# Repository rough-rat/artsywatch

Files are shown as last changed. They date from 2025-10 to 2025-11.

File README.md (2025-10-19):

# artsywatch

## Licensing Note

This project uses footprints, symbols and and 3D models converted via the
[easy2kicad](https://github.com/uPesy/easyeda2kicad.py) project.
These are derived from publicly available EasyEDA/JLCPCB component data,
used here solely to support reproducibility of this open hardware design.
All trademarks and component data belong to their respective owners.

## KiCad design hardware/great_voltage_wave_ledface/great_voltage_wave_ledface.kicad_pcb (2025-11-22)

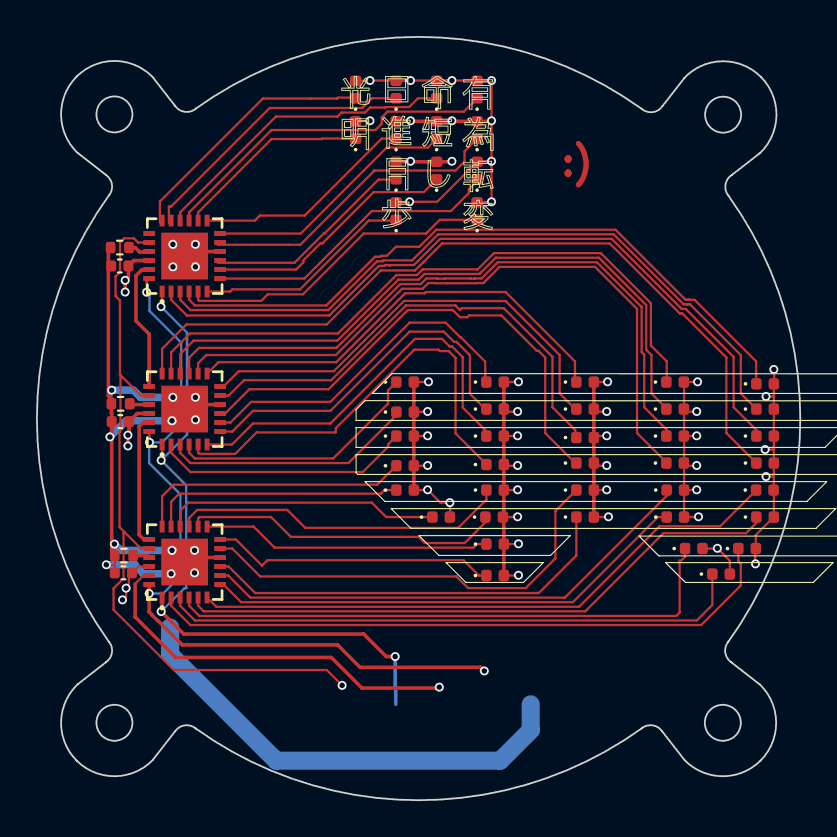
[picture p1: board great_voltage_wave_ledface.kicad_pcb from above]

Board: 2 copper layers, 42.4 x 42.4 mm, 58 parts (1 on the bottom side), 59 nets.

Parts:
C3, C10, C16: 470n; C_0402_1005Metric
D3, D4, D5, D6, D7, D8, D9, D10, D11, D12, D13, D14, D15, D16, D17, D18, D19, D20, D21, D22, D23, D24, D25, D26, D27, D28, D29, D30, D31, D32, D33, D34, D35, D36, D37, D38, D39, D40, D41, D42, D43, D44, D45, D46, D47, D48, D49, D50: LED; LED_0402_1005Metric
J1: Conn_01x06; CONN-SMD_GT-BTP25006-0300A-010A
R14, R16, R19: 510; R_0402_1005Metric
U101, U102, U103: FM6126QC; TQFN-24_L4.0-W4.0-P0.50-BL-EP2.6

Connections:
/DAT: J1.4, U101.23 (SDI)
/LAT: J1.3, U101.1 (LE), U102.1 (LE), U103.1 (LE)
/OE: J1.2, U101.20 (OE), U102.20 (OE), U103.20 (OE)
/SCLK: J1.5, U101.24 (CLK), U102.24 (CLK), U103.24 (CLK)
GND: C3.2, C10.2, C16.2, J1.6, R14.2, R16.2, R19.2, U101.10 (GND), U101.25 (EP), U102.10 (GND), U102.25 (EP), U103.10 (GND), U103.25 (EP)
unnamed: D3.1 (K), U103.18 (~OUT15)
unnamed: D4.1 (K), U103.17 (~OUT14)
unnamed: D5.1 (K), U103.16 (~OUT13)
unnamed: D6.1 (K), U103.15 (~OUT12)
unnamed: D7.1 (K), U103.14 (~OUT11)
unnamed: D8.1 (K), U103.13 (~OUT10)
unnamed: D9.1 (K), U103.12 (~OUT9)
unnamed: D10.1 (K), U103.11 (~OUT8)
unnamed: D11.1 (K), U103.9 (~OUT7)
unnamed: D12.1 (K), U103.8 (~OUT6)
unnamed: D13.1 (K), U103.7 (~OUT5)
unnamed: D14.1 (K), U103.6 (~OUT4)
unnamed: D15.1 (K), U103.5 (~OUT3)
unnamed: D16.1 (K), U103.4 (~OUT2)
unnamed: D17.1 (K), U103.3 (~OUT1)
unnamed: D18.1 (K), U103.2 (~OUT0)
unnamed: D19.1 (K), U102.2 (~OUT0)
unnamed: D20.1 (K), U102.3 (~OUT1)
unnamed: D21.1 (K), U102.4 (~OUT2)
unnamed: D22.1 (K), U102.5 (~OUT3)
unnamed: D23.1 (K), U102.6 (~OUT4)
unnamed: D24.1 (K), U102.7 (~OUT5)
unnamed: D25.1 (K), U102.8 (~OUT6)
unnamed: D26.1 (K), U102.9 (~OUT7)
unnamed: D27.1 (K), U102.11 (~OUT8)
unnamed: D28.1 (K), U102.12 (~OUT9)
unnamed: D29.1 (K), U102.13 (~OUT10)
unnamed: D30.1 (K), U102.14 (~OUT11)
unnamed: D31.1 (K), U102.15 (~OUT12)
unnamed: D32.1 (K), U102.16 (~OUT13)
unnamed: D33.1 (K), U102.17 (~OUT14)
unnamed: D34.1 (K), U102.18 (~OUT15)
unnamed: D35.1 (K), U101.2 (~OUT0)
unnamed: D36.1 (K), U101.3 (~OUT1)
unnamed: D37.1 (K), U101.4 (~OUT2)
unnamed: D38.1 (K), U101.5 (~OUT3)
unnamed: D39.1 (K), U101.6 (~OUT4)
unnamed: D40.1 (K), U101.7 (~OUT5)
unnamed: D41.1 (K), U101.8 (~OUT6)
unnamed: D42.1 (K), U101.9 (~OUT7)
unnamed: D43.1 (K), U101.11 (~OUT8)
unnamed: D44.1 (K), U101.12 (~OUT9)
unnamed: D45.1 (K), U101.13 (~OUT10)
unnamed: D46.1 (K), U101.14 (~OUT11)
unnamed: D47.1 (K), U101.15 (~OUT12)
unnamed: D48.1 (K), U101.16 (~OUT13)
unnamed: D49.1 (K), U101.17 (~OUT14)
unnamed: D50.1 (K), U101.18 (~OUT15)
unnamed: R14.1, U101.21 (REXT)
unnamed: U101.19 (SDO), U102.23 (SDI)
unnamed: R16.1, U102.21 (REXT)
unnamed: U102.19 (SDO), U103.23 (SDI)
unnamed: R19.1, U103.21 (REXT)
VDD: C3.1, C10.1, C16.1, D3.2 (A), D4.2 (A), D5.2 (A), D6.2 (A), D7.2 (A), D8.2 (A), D9.2 (A), D10.2 (A), D11.2 (A), D12.2 (A), D13.2 (A), D14.2 (A), D15.2 (A), D16.2 (A), D17.2 (A), D18.2 (A), D19.2 (A), D20.2 (A), D21.2 (A), D22.2 (A), D23.2 (A), D24.2 (A), D25.2 (A), D26.2 (A), D27.2 (A), D28.2 (A), D29.2 (A), D30.2 (A), D31.2 (A), D32.2 (A), D33.2 (A), D34.2 (A), D35.2 (A), D36.2 (A), D37.2 (A), D38.2 (A), D39.2 (A), D40.2 (A), D41.2 (A), D42.2 (A), D43.2 (A), D44.2 (A), D45.2 (A), D46.2 (A), D47.2 (A), D48.2 (A), D49.2 (A), D50.2 (A), J1.1, U101.22 (VDD), U102.22 (VDD), U103.22 (VDD)

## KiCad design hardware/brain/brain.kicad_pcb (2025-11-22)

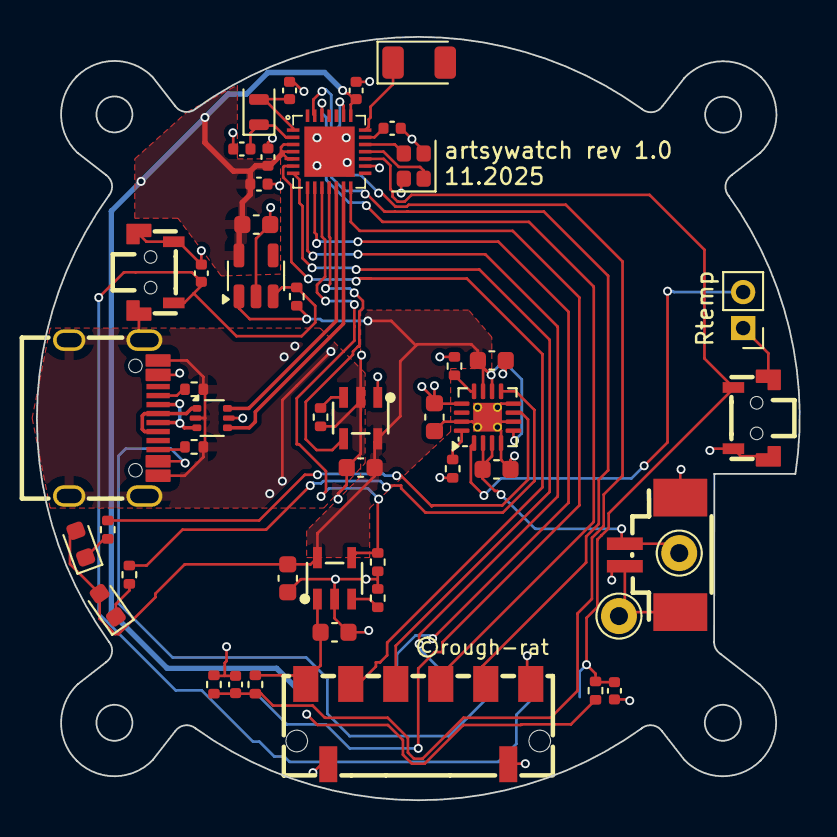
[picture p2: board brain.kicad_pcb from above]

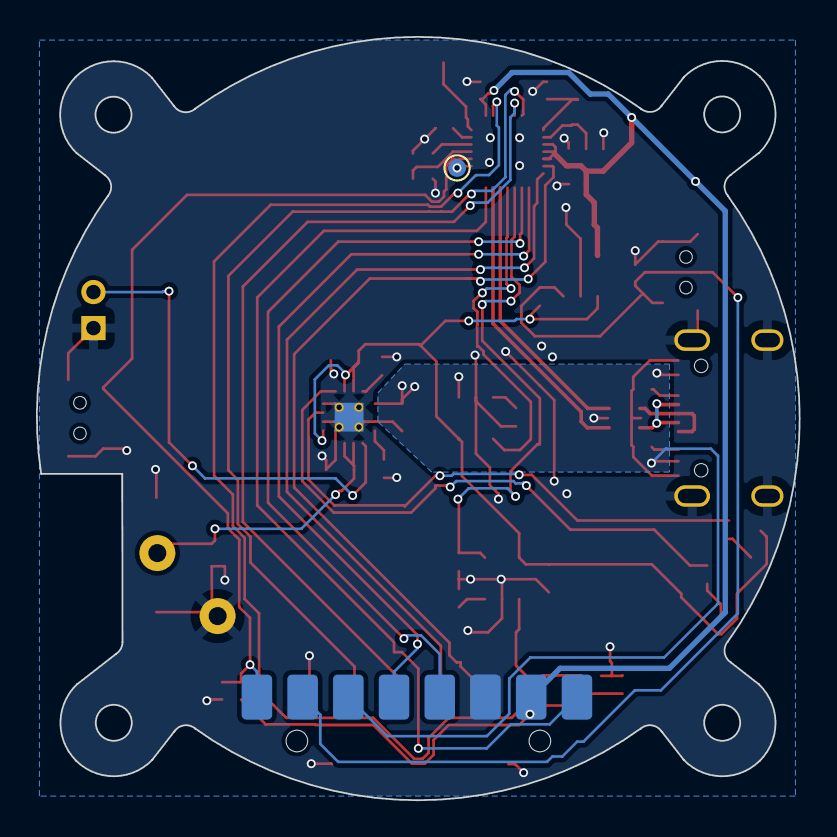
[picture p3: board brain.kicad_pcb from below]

Board: 2 copper layers, 42.4 x 42.4 mm, 50 parts (2 on the bottom side), 40 nets.

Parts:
AE1: Antenna_Chip; Johanson_2450AT18x100
C1, C4, C5, C6, C7, C8, C20: 10u; C_0603_1608Metric
C9, C13, C15, C17: 100n; C_0402_1005Metric
C11, C12, C14: 2.2uF; C_0402_1005Metric
C18, C19: 12p; C_0402_1005Metric
CN1: GT-BTP25006-0300A-010A; CONN-SMD_GT-BTP25006-0300A-010A
D1: LED_WHITE; LED_0603_1608Metric
D2: LED_RED; LED_0603_1608Metric
J5: Conn_01x08; PinSocket_1x08_P2.54mm_Vertical
P1: 1.25T-2PWT; CONN-SMD_P1.25-H_1.25T-2PWT
R1, R3: 5.1k; R_0402_1005Metric
R2, R4, R5, R12, R17, R20: 10k; R_0402_1005Metric
R6, R7: 3k; R_0402_1005Metric
R10, R11, R13: 100k; R_0402_1005Metric
SW1, SW2: TS24CA; SW-SMD_2P-TS24CA
TP1, TP2: TestPoint; Pin_D1.0mm_L10.0mm
TP3: TestPoint_2Pole; PinHeader_1x02_P2.00mm_Vertical
TP4: RX; TestPoint_Pad_D1.0mm
U1: USBLC6-2P6; SOT-666
U2: SPX3819M5-L-3-3; SOT-23-5
U3: BQ24073RGT; VQFN-16-1EP_3x3mm_P0.5mm_EP1.6x1.6mm_ThermalVias
U4, U5: LPW5209AB5F; SOT-23-5_L3.0-W1.7-P0.95-LS2.8-BL
U6: CH582F_C3001175; QFN-28_L4.0-W4.0-P0.40-BL-EP2.8
USBC1: TYPE-C-31-M-12; USB-C_SMD-TYPE-C-31-M-12_1
Y1: XO-32K; Crystal_SMD_2012-2Pin_2.0x1.2mm
Y2: 32 MHz; Crystal_SMD_2016-4Pin_2.0x1.6mm

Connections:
+4V: C4.1, C7.1, C20.1, D1.2 (A), D2.2 (A), R2.1, U2.1 (IN), U3.5 (EN2), U3.10 (OUT), U3.11 (OUT), U4.5 (VIN), U5.5 (VIN)
/4V_ENA: R11.2, U4.4 (EN), U6.10 (PB13/U2D+/SCK0_/SCL/TXD1_)
/4V_OUT: C8.1, CN1.1, R10.2, U4.1 (VOUT)
/BOOT: C17.1, J5.8, R17.1, SW2.1, U6.17 (PB22/TMR3/RXD2)
/BQ_CHG: R5.1, U3.9 (~CHG)
/BQ_PGOOD: R4.1, U3.7 (~PGOOD)
/CONN_DN: U1.3 (I/O2), USBC1.A7 (DN1), USBC1.B7 (DN2)
/CONN_DP: U1.1 (I/O1), USBC1.A6 (DP1), USBC1.B6 (DP2)
/DAT: CN1.4, U6.26 (PA14/MOSI/TXD0_/AIN4)
/LAT: CN1.3, U6.7 (PA9/TMR0/TXD1/AIN13)
/LIPO+: C6.1, P1.1, TP1.1, U3.2 (BAT), U3.3 (BAT)
/OE: CN1.2, U6.6 (PA8/RXD1/AIN12)
/PWR_CUTOFF: C15.1, J5.7, R2.2, SW1.1, U2.3 (EN)
/SCLK: CN1.5, U6.27 (PA13/SCK0/PWM5/AIN3)
/TCK: J5.5, U6.8 (PB15/TCK/MISO_/DTR_)
/TIO: J5.4, U6.9 (PB14/TIO/DSR_/MOSI_/PWM10)
/TX: J5.1, U6.14 (PB7/TXD0/PWM9)
/USB_BACKFEED_ENA: U5.4 (EN), U6.11 (PB12/U2D-/SCS_/SDA/RXD1_)
/USB_DN: U1.4 (I/O2), U6.13 (PB10/UD-/TMR1_)
/USB_DP: U1.6 (I/O1), U6.12 (PB11/UD+/TMR2_)
/VBAT_MEAS: C9.1, R10.1, R13.2, U6.23 (PA4/RXD3/AIN0)
/X32I: U6.19 (X32MI), Y2.3
/X32O: U6.18 (X32MO), Y2.1
/nRST: TP4.1, U6.16 (PB23/RST/TMR0_/TXD2_/PWM11)
GND: C1.2, C4.2, C5.2, C6.2, C7.2, C8.2, C9.2, C11.2, C12.2, C13.2, C14.1, C15.2, C17.2, C18.2, C19.2, C20.2, CN1.6, CN1.7, CN1.8, J5.3, P1.2, P1.3, P1.4, R1.2, R3.2, R6.1, R7.1, R11.1, R12.1, R13.1, R20.1, SW1.2, SW1.3, SW1.4, SW2.2, SW2.3, SW2.4, TP2.1, TP3.1, U1.2 (GND), U2.2 (GND), U3.4 (~CE), U3.6 (EN1), U3.8 (VSS), U3.15 (TD), U3.17 (VSS), U4.2 (GND), U5.2 (GND), U6.29 (EP), USBC1.1 (EH), USBC1.2 (EH), USBC1.3 (EH), USBC1.4 (EH), USBC1.A1B12 (GND), USBC1.B1A12 (GND), Y2.2, Y2.4
unnamed: AE1.1 (FEED), U6.21 (ANT)
unnamed: D1.1 (K), R4.2
unnamed: D2.1 (K), R5.2
unnamed: R6.2, U3.12 (ILIM)
unnamed: R7.2, U3.16 (ISET)
unnamed: TP3.2, U3.1 (TS)
unnamed: R12.2, U4.3 (ISET)
unnamed: R20.2, U5.3 (ISET)
unnamed: C18.1, U6.2 (PA10/X32KI/TMR1), Y1.1
unnamed: C19.1, U6.1 (PA11/X32KO/TMR2), Y1.2
unnamed: C14.2, U6.20 (VINTA)
unnamed: R3.1, USBC1.A5 (CC1)
unnamed: R1.1, USBC1.B5 (CC2)
VBUS: C1.1, J5.6, U1.5 (VBUS), U3.13 (IN), U5.1 (VOUT), USBC1.A4B9 (VBUS), USBC1.B4A9 (VBUS)
VDD: C5.1, C11.1, C12.1, C13.1, J5.2, R17.2, U2.5 (OUT), U6.3 (VDCID), U6.4 (VSW), U6.5 (VIO33/VDD33), U6.22 (VDCIA)

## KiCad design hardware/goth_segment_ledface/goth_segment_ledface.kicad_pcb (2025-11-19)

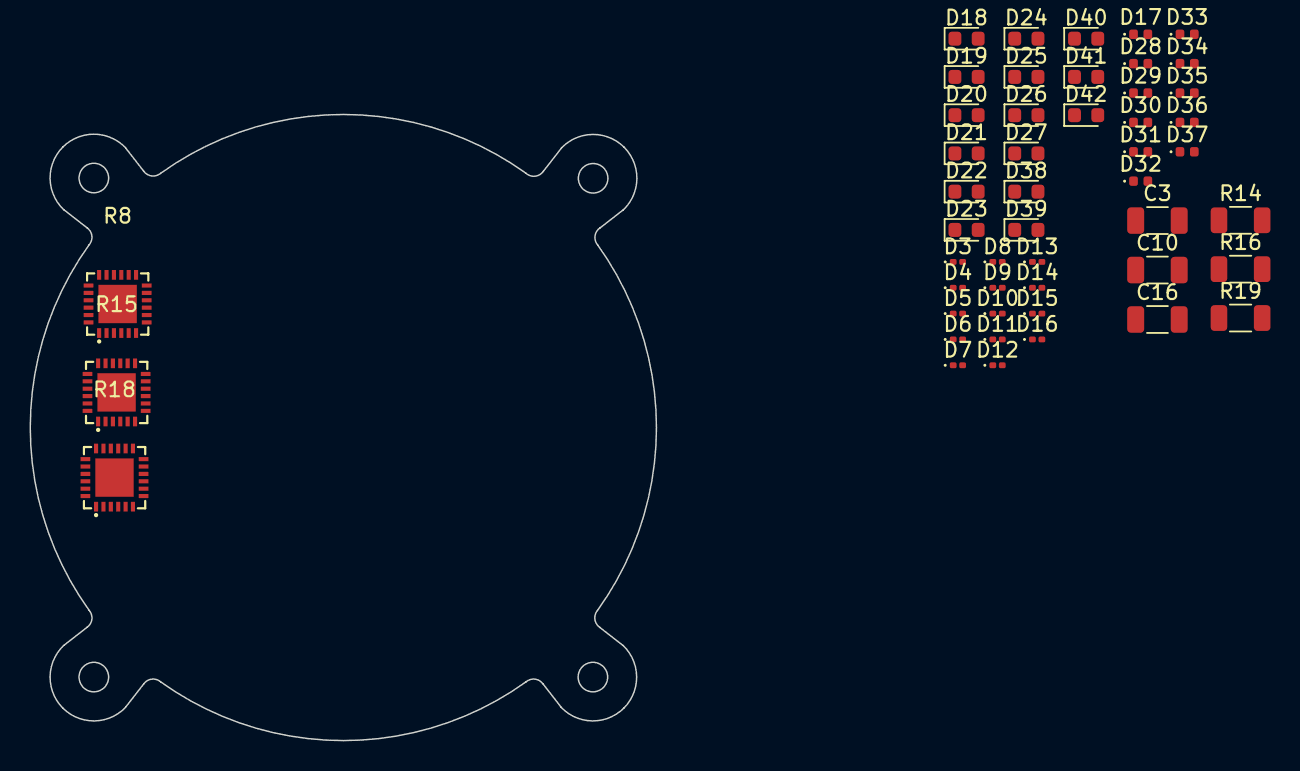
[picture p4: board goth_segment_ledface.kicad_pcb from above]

Board: 2 copper layers, 42.4 x 42.4 mm, 49 parts (0 on the bottom side), 50 nets, no tracks yet.

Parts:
C3, C10, C16: 470n; C_1206_3216Metric
D3, D4, D5, D6, D7, D8, D9, D10, D11, D12, D13, D14, D15, D16: LED; LED_0201_0603Metric
D17, D28, D29, D30, D31, D32, D33, D34, D35, D36, D37: LED; LED_0402_1005Metric
D18, D19, D20, D21, D22, D23, D24, D25, D26, D27, D38, D39, D40, D41, D42: LED; LED_0603_1608Metric
R8, R15, R18: FM6126QC; TQFN-24_L4.0-W4.0-P0.50-BL-EP2.6
R14, R16, R19: 510; R_1206_3216Metric

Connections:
/LAT: R8.1 (LE), R15.1 (LE), R18.1 (LE)
/OE: R8.20 (OE), R15.20 (OE), R18.20 (OE)
/SCLK: R8.24 (CLK), R15.24 (CLK), R18.24 (CLK)
GND: C3.2, C10.2, C16.2, R8.10 (GND), R8.25 (EP), R14.2, R15.10 (GND), R15.25 (EP), R16.2, R18.10 (GND), R18.25 (EP), R19.2
unnamed: D3.2 (A), R8.2 (~OUT0)
unnamed: D4.2 (A), R8.3 (~OUT1)
unnamed: D5.2 (A), R8.4 (~OUT2)
unnamed: D6.2 (A), R8.5 (~OUT3)
unnamed: D7.2 (A), R8.6 (~OUT4)
unnamed: D8.2 (A), R8.7 (~OUT5)
unnamed: D9.2 (A), R8.8 (~OUT6)
unnamed: D10.2 (A), R8.9 (~OUT7)
unnamed: D11.2 (A), R8.11 (~OUT8)
unnamed: D12.2 (A), R8.12 (~OUT9)
unnamed: D13.2 (A), R8.13 (~OUT10)
unnamed: D14.2 (A), R8.14 (~OUT11)
unnamed: D15.2 (A), R8.15 (~OUT12)
unnamed: D16.2 (A), R8.16 (~OUT13)
unnamed: D17.2 (A), R8.17 (~OUT14)
unnamed: D18.2 (A), R8.18 (~OUT15)
unnamed: D19.2 (A), R15.2 (~OUT0)
unnamed: D20.2 (A), R15.3 (~OUT1)
unnamed: D21.2 (A), R15.4 (~OUT2)
unnamed: D22.2 (A), R15.5 (~OUT3)
unnamed: D23.2 (A), R15.6 (~OUT4)
unnamed: D24.2 (A), R15.7 (~OUT5)
unnamed: D25.2 (A), R15.8 (~OUT6)
unnamed: D26.2 (A), R15.9 (~OUT7)
unnamed: D27.2 (A), R15.11 (~OUT8)
unnamed: D28.2 (A), R15.12 (~OUT9)
unnamed: D29.2 (A), R15.13 (~OUT10)
unnamed: D30.2 (A), R15.14 (~OUT11)
unnamed: D31.2 (A), R15.15 (~OUT12)
unnamed: D32.2 (A), R15.16 (~OUT13)
unnamed: D33.2 (A), R15.17 (~OUT14)
unnamed: D34.2 (A), R15.18 (~OUT15)
unnamed: D35.2 (A), R18.2 (~OUT0)
unnamed: D36.2 (A), R18.3 (~OUT1)
unnamed: D37.2 (A), R18.4 (~OUT2)
unnamed: D38.2 (A), R18.5 (~OUT3)
unnamed: D39.2 (A), R18.6 (~OUT4)
unnamed: D40.2 (A), R18.7 (~OUT5)
unnamed: D41.2 (A), R18.8 (~OUT6)
unnamed: D42.2 (A), R18.9 (~OUT7)
unnamed: R8.21 (REXT), R14.1
unnamed: R15.21 (REXT), R16.1
unnamed: R8.19 (SDO), R15.23 (SDI)
unnamed: R15.19 (SDO), R18.23 (SDI)
unnamed: R18.21 (REXT), R19.1
VDD: C3.1, C10.1, C16.1, R8.22 (VDD), R15.22 (VDD), R18.22 (VDD)

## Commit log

2025-10-18 @tym2k1 you go
    [artsywatch.kicad_pcb, artsywatch.kicad_sch]
2025-10-18 chore: move project to separate dir
    [artsywatch.kicad_pcb, artsywatch.kicad_sch]
2025-10-19 feat: add Project Symbols/Footprints
2025-10-19 feat: modify FM6126QC footprint
2025-10-19 feat: use the project's FM6126QC
    [artsywatch.kicad_sch]
2025-10-19 feat: fix symbol/footprint naming to more standarized
    [artsywatch.kicad_sch]
2025-10-19 chore: make git track 3D files
2025-10-19 feat: modify CH582F footprint
2025-10-19 feat: change switches to TS24CA
    [artsywatch.kicad_sch]
2025-10-19 chore: disable GT-USB-7055E USB-C, to be replaced
    [artsywatch.kicad_sch]
2025-10-20 feat: initial pcb design
    [artsywatch.kicad_pcb]
2025-10-20 feat: initial led placement
    [artsywatch.kicad_pcb, artsywatch.kicad_sch]
2025-10-21 fix: change watchface size to proper radius
    Was in diameter not radius
    [artsywatch.kicad_pcb, artsywatch.kicad_sch]
2025-10-21 feat: initial great voltage wave watchface
    [artsywatch.kicad_pcb]
2025-10-23 feat: improved great voltage wave watchface
    [artsywatch.kicad_pcb]
2025-10-23 feat: swap USB-C port for TYPE-C-31-M-12
    [artsywatch.kicad_pcb, artsywatch.kicad_sch]
2025-10-23 feat: great voltage wave change poem and touch up
    [artsywatch.kicad_pcb]
2025-10-23 feat: great voltage wave PoC led placement
    [artsywatch.kicad_pcb]
2025-10-26 revert: add accidentaly deleted F.Mask to great voltage wave
    [artsywatch.kicad_pcb]
2025-11-05 copy some stuff from tama, support
    [artsywatch.kicad_pcb, artsywatch.kicad_sch]
2025-11-07 feat: don't populate LED's and register from schematic (2nd board)
    [artsywatch.kicad_sch]
2025-11-07 feat: add C2834312 via easyeda2kicad
    [artsywatch.kicad_sch]
2025-11-07 feat: initial placement
    [artsywatch.kicad_pcb]
2025-11-07 feat: add initial screw-holes
    [artsywatch.kicad_pcb]
2025-11-12 chore: separate into different KiCad projects
    [artsywatch.kicad_pcb, brain.kicad_pcb, brain.kicad_sch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]
2025-11-13 route wawatchbrain
    [brain.kicad_pcb, brain.kicad_sch]
2025-11-19 feat: improved screw holes
    [brain.kicad_pcb, goth_segment_ledface.kicad_pcb, great_voltage_wave_ledface.kicad_pcb]
2025-11-19 chore: fix 3D models rendering
    [brain.kicad_pcb]
2025-11-19 fix: fix footprint/symbol libs project paths
2025-11-19 feat: initial ledface/brain connector
    [goth_segment_ledface.kicad_pcb, great_voltage_wave_ledface.kicad_pcb]
2025-11-20 feat: great voltage wave final led placement
    [great_voltage_wave_ledface.kicad_pcb, great_voltage_wave_ledface.kicad_sch]
2025-11-22 brain order prepared
    [brain.kicad_pcb, brain.kicad_sch]
2025-11-22 voltage wave initial routing
    [great_voltage_wave_ledface.kicad_pcb, great_voltage_wave_ledface.kicad_sch]
2025-11-22 voltage wave routed
    [great_voltage_wave_ledface.kicad_pcb, great_voltage_wave_ledface.kicad_sch]
2025-11-22 forgor save pcb file
    [great_voltage_wave_ledface.kicad_pcb]
2026-01-04 feat(voltage wave): add screw-holes to watchface (same size as brain/ledface)

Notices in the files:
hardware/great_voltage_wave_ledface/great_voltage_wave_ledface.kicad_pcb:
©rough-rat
